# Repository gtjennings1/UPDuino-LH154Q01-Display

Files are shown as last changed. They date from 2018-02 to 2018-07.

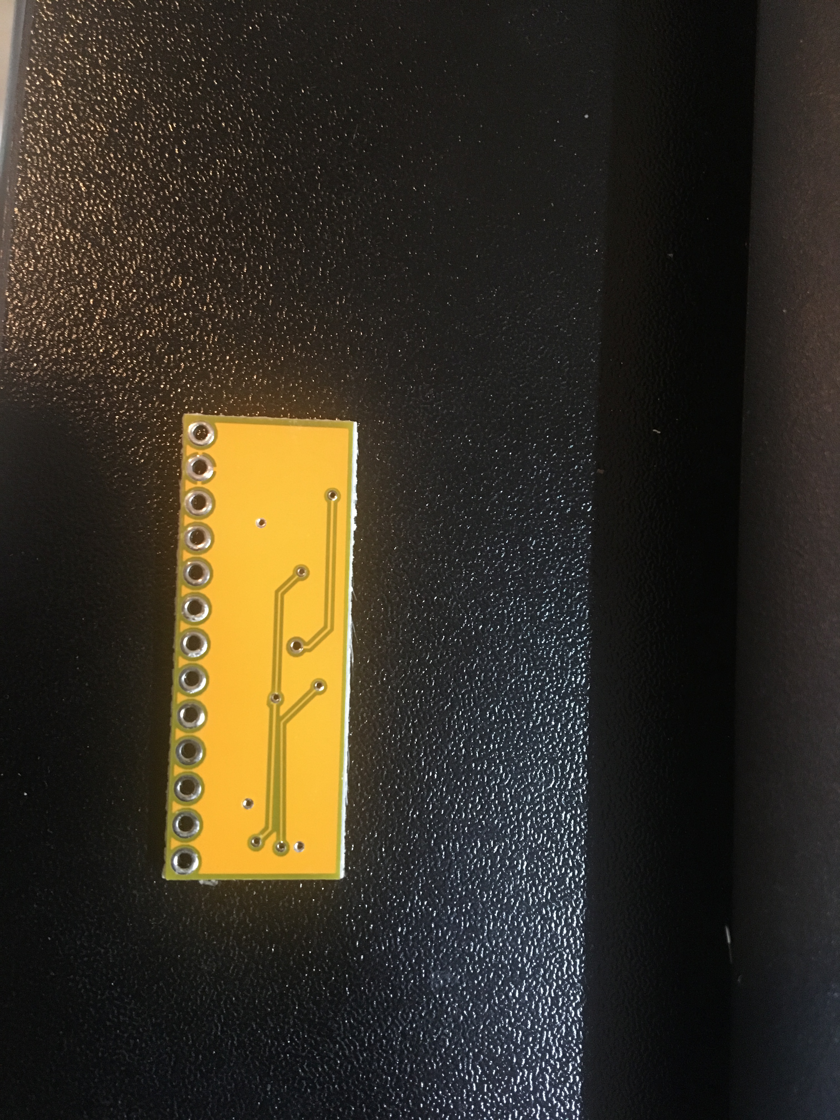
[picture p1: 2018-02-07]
PCB/Images/IMG-0591.JPG

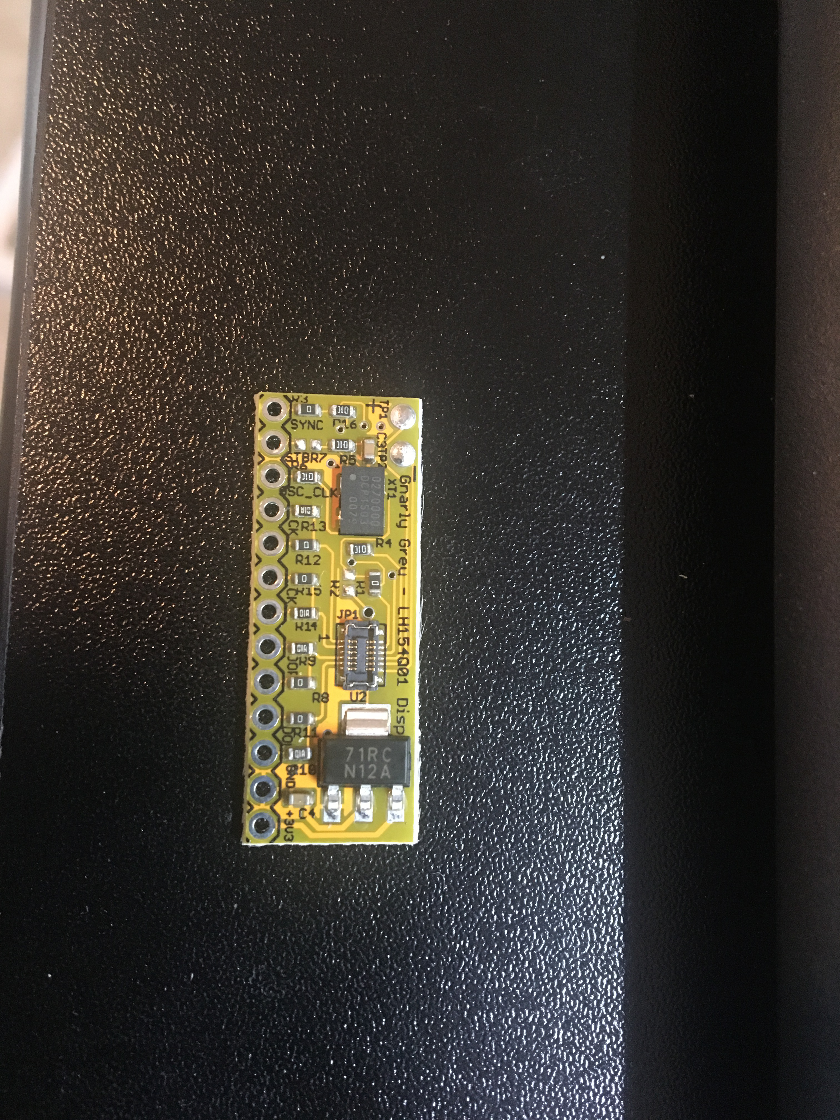
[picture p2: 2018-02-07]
PCB/Images/IMG-0590.JPG

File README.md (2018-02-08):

# UPDuino-LH154Q01-Display
Design to connect Lattice Ultraplus FPGA to LH154Q01 Display

UPDuino is a small maker board with a Lattice Ultraplus mobile FPGA.  The UPDuino LH154 Display Adapter Board provides the ability to attach a small 240x240 24-bit RGB display that has been used for many electronic devices including the iPod Nano (6th generation).  The FPGA can be used as a small graphics processor to deliver interactive graphics, bitmaps, fonts/text on the display.

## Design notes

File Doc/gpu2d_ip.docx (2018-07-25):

Gnarly Grey 2D GPU IP

7/25/18

The Gnarly Grey 2D GPU IP supports acceleration functions for drawing line, rectangle, circle, triangle and filling up rectangle, circle and triangle inside a very small Lattice Ultraplus 5K LUT FPGA. There’s also support for mono-color 64x64 pixel bitmap and fonts with variable size. The GPU can be controlled with very simple interface like UART to receive its commands or register configurations with very low bandwidth. Rendered graphics from these settings are passed to a RAM/Display Buffer. Current implementation of supports 12-bit (4096) colors (4-bits for R, G, B each).

IP Block Diagram

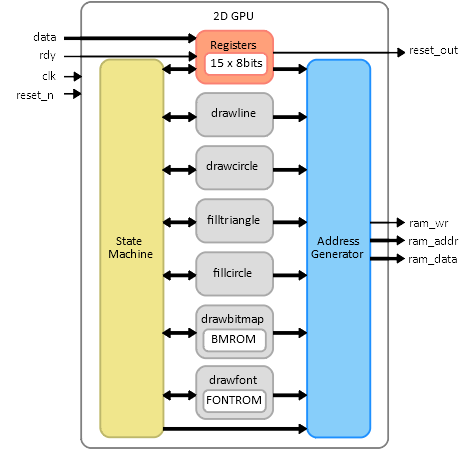
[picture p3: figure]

The GPU IP has 15 registers to store information related to GPU task such as graphic coordinates, GPU functions to be execute, color bitmap number, font character and size, etc. Information stored in registers is utilized by a state machine, address generator and acceleration sub modules (drawline, drawcircle, filltriangle, etc.) to perform the given acceleration task. A state machine enables acceleration sub modules based on information configured in the register set and the address generator takes data from acceleration sub module to write rendering information on display buffer.

The GPU IP is designed to take register address and data information from the same input bus. It takes the first data received on the bus as the address and second data received as the data.

There’s facility to connect multiple GPU (up to 15) on same bus and controlling all GPU (Display) simultaneously or individually by using broadcast or individual control/status registers as mentioned in Register Map section. A display number for particular instance can be set by a Verilog parameter at synthesis time. There’s also a Verilog parameter for rotation, in case other than 0 degree rotation is required.

Port and Parameter Details:

Name | Type | Size (bits) | Description
ROTATION | Parameter | 2 | 2’b00 – 0 degree rotation 2’b01 – 90 degree rotation 2’b10 – 180 degree rotation 2’b11 – 270 degree rotation
DISPLAY_NO | Parameter | 4 | Value from 1 (4’h0001) to 15 (4’h1111)
clk | Input | 1 | Clock
reset_n | Input | 1 | Reset – Active Low
rdy | Input | 1 | Ready – Active High
data | Input | 8 | Data – used for register address and data
reset_out | Output | 1 | Reset Out – Active High
ram_wr | Output | 1 | Memory Write Enable – Active High
ram_addr | Output | 20 | Memory Write Address
ram_data | Output | 8 | Memory Write Data

Register Map

Following is description of registers available on IP, all registers take 00h as default value upon reset.

Register Address 00h – Control/Status Register [Boardcast]

Bit 7 | Bit 6 | Bit 5 | Bit 4 | Bit 3 | Bit 2 | Bit 1 | Bit 0
START | BUSY | RESET | NU | FUN[3] | FUN[2] | FUN[1] | FUN[0]

| FUN[3:0] 0000 0001 0010 0011 0100 0101 0110 0111 1000 1001 | Draw Function pixel line rectangle triangle circle fill rectangle fill triangle fill circle bitmap font
| NU | Not Used
| RESET 0 1 | Reset GPU and generate reset_out No effect Reset, self clearing
| BUSY 0 1 | GPU busy status GPU is free to accept new request GPU is busy
| START 0 1 | Trigger/Start execution of acceleration function No effect Start, self clearing

Register Address 01h – Red Color Register

Bit 7 | Bit 6 | Bit 5 | Bit 4 | Bit 3 | Bit 2 | Bit 1 | Bit 0
RED[3] | RED[2] | RED[1] | RED[0] | NU | NU | NU | NU

| NU | Not Used
| RED[3:0] | Red Color Value (0 to 15)

Register Address 02h – Green Color Register

Bit 7 | Bit 6 | Bit 5 | Bit 4 | Bit 3 | Bit 2 | Bit 1 | Bit 0
GREEN[3] | GREEN[2] | GREEN[1] | GREEN[0] | NU | NU | NU | NU

| NU | Not Used
| GREEN[3:0] | Green Color Value (0 to 15)

Register Address 03h – Blue Color Register

Bit 7 | Bit 6 | Bit 5 | Bit 4 | Bit 3 | Bit 2 | Bit 1 | Bit 0
BLUE[3] | BLUE[2] | BLUE[1] | BLUE[0] | NU | NU | NU | NU

| NU | Not Used
| BLUE[3:0] | Blue Color Value (0 to 15)

Register Address 04h – Point 1, X Co-ordinate Register

Bit 7 | Bit 6 | Bit 5 | Bit 4 | Bit 3 | Bit 2 | Bit 1 | Bit 0
X1[7] | X1[6] | X1[5] | X1[4] | X1[3] | X1[2] | X1[1] | X1[0]

| X1[7:0] | Point 1, X Co-ordinate Value (0 to 255)

Register Address 05h – Point 1, Y Co-ordinate Register

Bit 7 | Bit 6 | Bit 5 | Bit 4 | Bit 3 | Bit 2 | Bit 1 | Bit 0
Y1[7] | Y1[6] | Y1[5] | Y1[4] | Y1[3] | Y1[2] | Y1[1] | Y1[0]

| Y1[7:0] | Point 1, Y Co-ordinate Value (0 to 255)

Register Address 06h – Point 2, X Co-ordinate Register

Bit 7 | Bit 6 | Bit 5 | Bit 4 | Bit 3 | Bit 2 | Bit 1 | Bit 0
X2[7] | X2[6] | X2[5] | X2[4] | X2[3] | X2[2] | X2[1] | X2[0]

| X2[7:0] | Point 2, X Co-ordinate Value (0 to 255)

Register Address 07h – Point 2, Y Co-ordinate Register

Bit 7 | Bit 6 | Bit 5 | Bit 4 | Bit 3 | Bit 2 | Bit 1 | Bit 0
Y2[7] | Y2[6] | Y2[5] | Y2[4] | Y2[3] | Y2[2] | Y2[1] | Y2[0]

| Y2[7:0] | Point 2, Y Co-ordinate Value (0 to 255)

Register Address 08h – Point 3, X Co-ordinate Register

Bit 7 | Bit 6 | Bit 5 | Bit 4 | Bit 3 | Bit 2 | Bit 1 | Bit 0
X3[7] | X3[6] | X3[5] | X3[4] | X3[3] | X3[2] | X3[1] | X3[0]

| X3[7:0] | Point 3, X Co-ordinate Value (0 to 255)

Register Address 09h – Point 3, Y Co-ordinate Register

Bit 7 | Bit 6 | Bit 5 | Bit 4 | Bit 3 | Bit 2 | Bit 1 | Bit 0
Y3[7] | Y3[6] | Y3[5] | Y3[4] | Y3[3] | Y3[2] | Y3[1] | Y3[0]

| Y3[7:0] | Point 3, Y Co-ordinate Value (0 to 255)

Register Address 0Ah – Circle Radius Register

Bit 7 | Bit 6 | Bit 5 | Bit 4 | Bit 3 | Bit 2 | Bit 1 | Bit 0
RAD[7] | RAD[6] | RAD[5] | RAD[4] | RAD[3] | RAD[2] | RAD[1] | RAD[0]

| RAD[7:0] | Circle Radius Value (0 to 255)

Register Address 0Bh – Bitmap Number Register

Bit 7 | Bit 6 | Bit 5 | Bit 4 | Bit 3 | Bit 2 | Bit 1 | Bit 0
NU | NU | NU | BMN[4] | BMN[3] | BMN[2] | BMN[1] | BMN[0]

| BMN[4:0] | Bitmap Number Value (0 to 23)
| NU | Not Used

Register Address 0Ch – Font Character Register

Bit 7 | Bit 6 | Bit 5 | Bit 4 | Bit 3 | Bit 2 | Bit 1 | Bit 0
FC[7] | FC[6] | FC[5] | FC[4] | FC[3] | FC[2] | FC[1] | FC[0]

| FC[7:0] | Font Character Value (0 to 255)

Register Address 0Dh – Font Size Register

Bit 7 | Bit 6 | Bit 5 | Bit 4 | Bit 3 | Bit 2 | Bit 1 | Bit 0
NU | NU | NU | FS[4] | FS[3] | FS[2] | FS[1] | FS[0]

| FS[4:0] | Font Size Value (1 to 31)
| NU | Not Used

Register Address X0h – Control/Status Register [Individual], X= Display No (1 to 15)

Bit 7 | Bit 6 | Bit 5 | Bit 4 | Bit 3 | Bit 2 | Bit 1 | Bit 0
START | BUSY | RESET | NU | FUN[3] | FUN[2] | FUN[1] | FUN[0]

| FUN[3:0] 0000 0001 0010 0011 0100 0101 0110 0111 1000 1001 | Draw Function pixel line rectangle triangle circle fill rectangle fill triangle fill circle bitmap font
| NU | Not Used
| RESET 0 1 | Reset GPU and generate reset_out No effect Reset, self clearing
| BUSY 0 1 | GPU busy status GPU is free to accept new request GPU is busy
| START 0 1 | Trigger/Start execution of acceleration function No effect Start, self clearing

Typical System Example:

In this example, a typical system using 2D GPU is showcased. The system consist of a microcontroller such as an Arduino Nano ATMega328 with a UART interface connected to Upduino v1.0 or v2.0 board. A LH154Q01 Display Adapter for UPDuino boards is used to connected a 240x240 pixel MIPI display on one end to the Upduino v1.0 or v2.0 board.

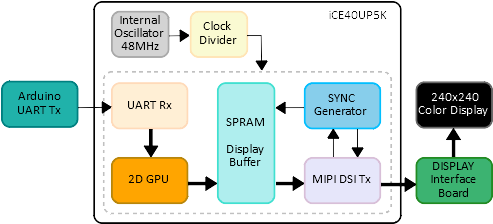
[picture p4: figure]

In this typical setup, Arduino Nano microcontroller is the host controller which control’s operation of GPU. Inside the iCE40UP5K FPGA, small UART receiver is used to receive commands from Arduino over UART and provide it to the 2D GPU. The 2D GPU is connected with 128kB Display Buffer (SPRAM) available on FPGA itself. The display buffer is accessed by a MIPI DSI transmitter design to send display buffer data to the 240x240 pixel color display through MIPI display interface board. SYNC Generator controls timing of sending display buffer to MIPI display.

The following are some typical examples of the GPU commands issued by the microcontroller over UART:

1. Draw a line from p1(10,20) to p2(50,60) with color Red.

Serial.write(0x04); //Register address for P1-x

Serial.write(0x0A); //Register data for P1-x

Serial.write(0x05); //Register address for P1-y

Serial.write(0x14); //Register data for P1-y

Serial.write(0x06); //Register address for P2-x

Serial.write(0x32); //Register data for P2-x

Serial.write(0x07); //Register address for P2-y

Serial.write(0x3C); //Register data for P2-y

Serial.write(0x01); //Register address for Red color

Serial.write(0xFF); //Register data for Red color

Serial.write(0x02); //Register address for Green color

Serial.write(0x00); //Register data for Green color

Serial.write(0x03); //Register address for Blue Color

Serial.write(0x00); //Register data for Blue Color

Serial.write(0x00); //Register address for Control/Status Register

Serial.write(0x81); //Register data for Control/Status Register to draw line

2. Draw a Yellow color filled triangle with p1(10,20), p2(50, 60), p3(10, 60)

Serial.write(0x04); //Register address for P1-x

Serial.write(0x0A); //Register data for P1-x

Serial.write(0x05); //Register address for P1-y

Serial.write(0x14); //Register data for P1-y

Serial.write(0x06); //Register address for P2-x

Serial.write(0x32); //Register data for P2-x

Serial.write(0x07); //Register address for P2-y

Serial.write(0x3C); //Register data for P2-y

Serial.write(0x08); //Register address for P3-x

Serial.write(0x0A); //Register data for P3-x

Serial.write(0x09); //Register address for P3-y

Serial.write(0x3C); //Register data for P3-y

Serial.write(0x01); //Register address for Red color

Serial.write(0xFF); //Register data for Red color

Serial.write(0x02); //Register address for Green color

Serial.write(0xFF); //Register data for Green color

Serial.write(0x03); //Register address for Blue Color

Serial.write(0x00); //Register data for Blue Color

Serial.write(0x00); //Register address for Control/Status Register

Serial.write(0x86); //Register data for Control/Status Register to fill triangle

3. Draw a bitmap number 5 at p1(10,20) with SkyBlue color

Serial.write(0x04); //Register address for P1-x

Serial.write(0x0A); //Register data for P1-x

Serial.write(0x05); //Register address for P1-y

Serial.write(0x14); //Register data for P1-y

Serial.write(0x01); //Register address for Red color

Serial.write(0x00); //Register data for Red color

Serial.write(0x02); //Register address for Green color

Serial.write(0xFF); //Register data for Green color

Serial.write(0x03); //Register address for Blue Color

Serial.write(0xFF); //Register data for Blue Color

Serial.write(0x0B); //Register address for Bitmap Number

Serial.write(0x05); //Register data for Bitmap Number

Serial.write(0x00); //Register address for Control/Status Register

Serial.write(0x88); //Register data for Control/Status Register to draw bitmap

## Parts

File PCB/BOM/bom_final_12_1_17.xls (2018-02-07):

EXAMPLE BILL OF MATERIALS (BOM)
Place your mouse over the red comment markers in the top right corner of the cells in the row below to see more info on the data in that column
1 | 2 | 3 | 4 | 5 | 6 | 7 | 8 | 9 | 10 | 11
Sequential Item Nos | Consolidated quantity of each Part No | Component ID's separated by Commas | Confirmation Yes or No Parts are fitted this Build (Note 1) | Full Description of Part e.g. for capacitor include value, tolerance and type or Dielectric | Value or Type No | Case Style | Supplier or Manufacturer (Note 2) | Supplier Stock No or Manufacturer's Part No (Note 2) | Side of Board Mounted | PTH or SMT
Item | Qty | Reference | Fit | Part Description | Value | Package | Supplier | Supplier Ref | Side | Mount Type
1 | 2 | C3, C4 | Y | cap | 0.1uF | Capacitor |  | 402 | T | S
2 | 1 | JP1 | Y | connector for display | 5035481220 | Connector |  |  | T | S
3 | 1 | JP2 | N | .1" header | DNI | 13-pin single row .1" header |  |  | T | P
4 | 8 | R1, R3, R8, R11, R12, R15, R6, R7 | Y | 0 ohm resistor | 0 | Resistor |  | 402 | T | S
5 | 1 | R2 | N | DNI resistors | DNI | Resistor |  | 402 | T | S
6 | 4 | R4, R5, R16 | Y | 10k resistors | 10k | Resistor |  | 402 | T | S
7 | 4 | R9, R10, R13, R14 | Y | 100 ohm resistors | 100 | Resistor |  | 402 | T | S
8 | 1 | U2 | Y | 1.8V regulator | LM1117MPX-1.8/NOPB | Voltage Regulator LM1117 |  | VREG-08170 | T | S
9 | 1 | XT1 | Y | 27Mhz Osc. | ASFLMB-50.000MHZ-LC-T |  |  | Use this osc or equivlent with same pinout | T | S

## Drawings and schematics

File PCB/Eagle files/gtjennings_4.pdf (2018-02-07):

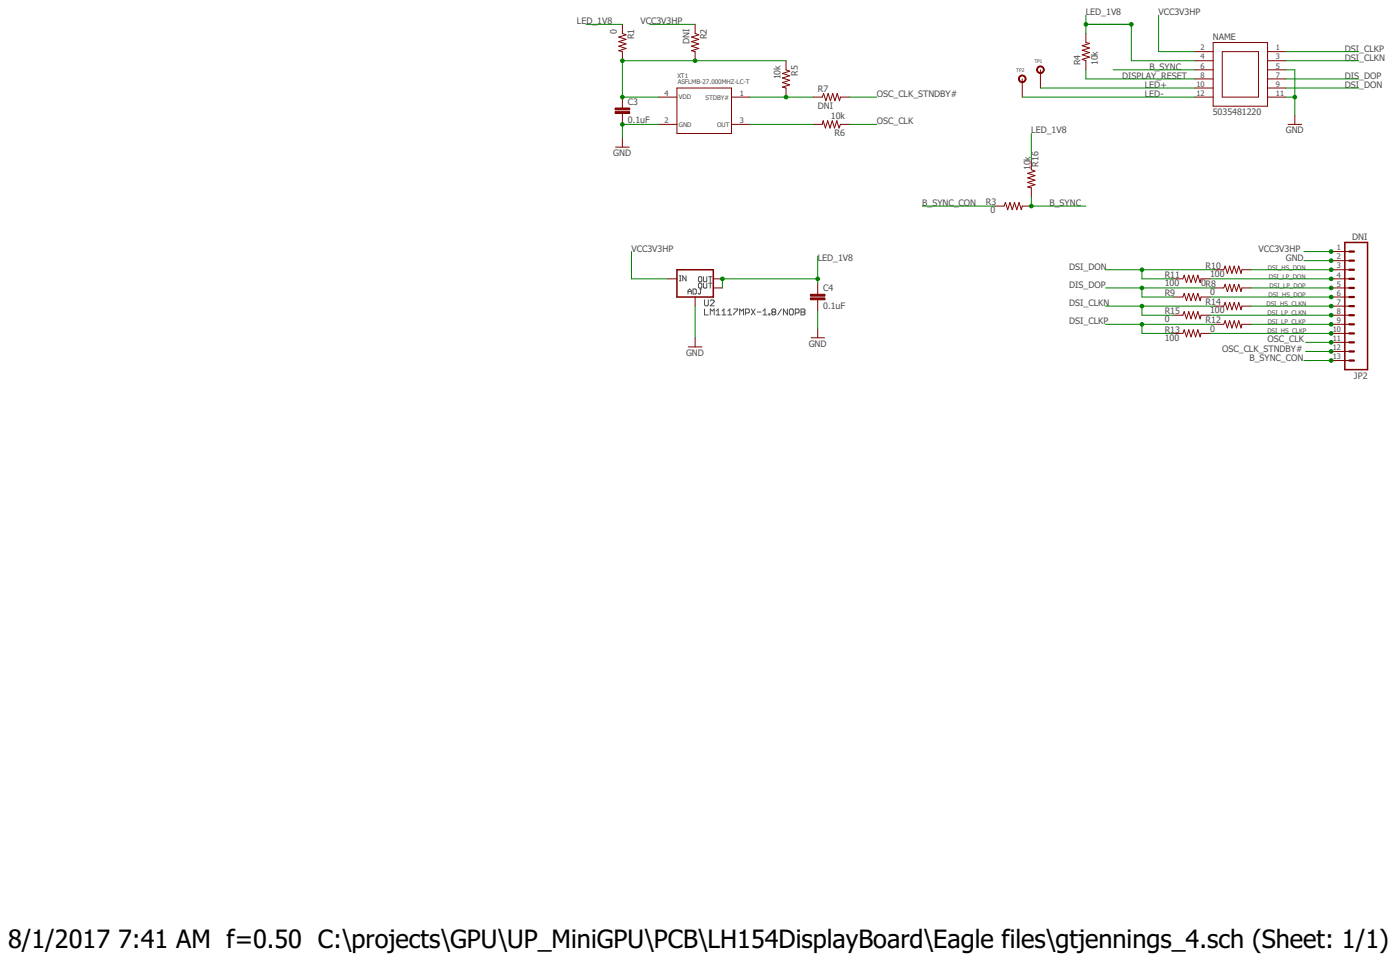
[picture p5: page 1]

8/1/2017 7:41 AM f=0.50 C:\projects\GPU\UP_MiniGPU\PCB\LH154DisplayBoard\Eagle files\gtjennings_4.sch (Sheet: 1/1)

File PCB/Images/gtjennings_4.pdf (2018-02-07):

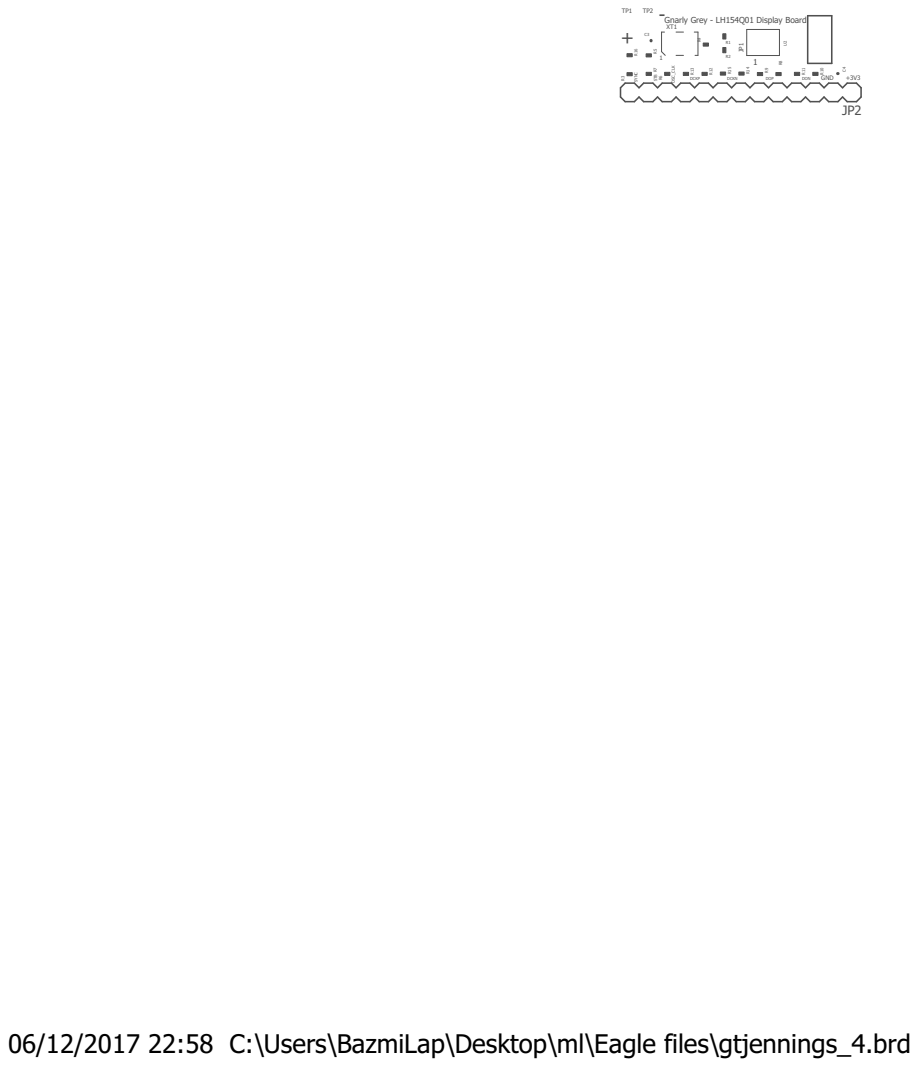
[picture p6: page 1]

-Gnarly Grey - LH154Q01 Display Board

06/12/2017 22:58 C:\Users\BazmiLap\Desktop\ml\Eagle files\gtjennings_4.brd

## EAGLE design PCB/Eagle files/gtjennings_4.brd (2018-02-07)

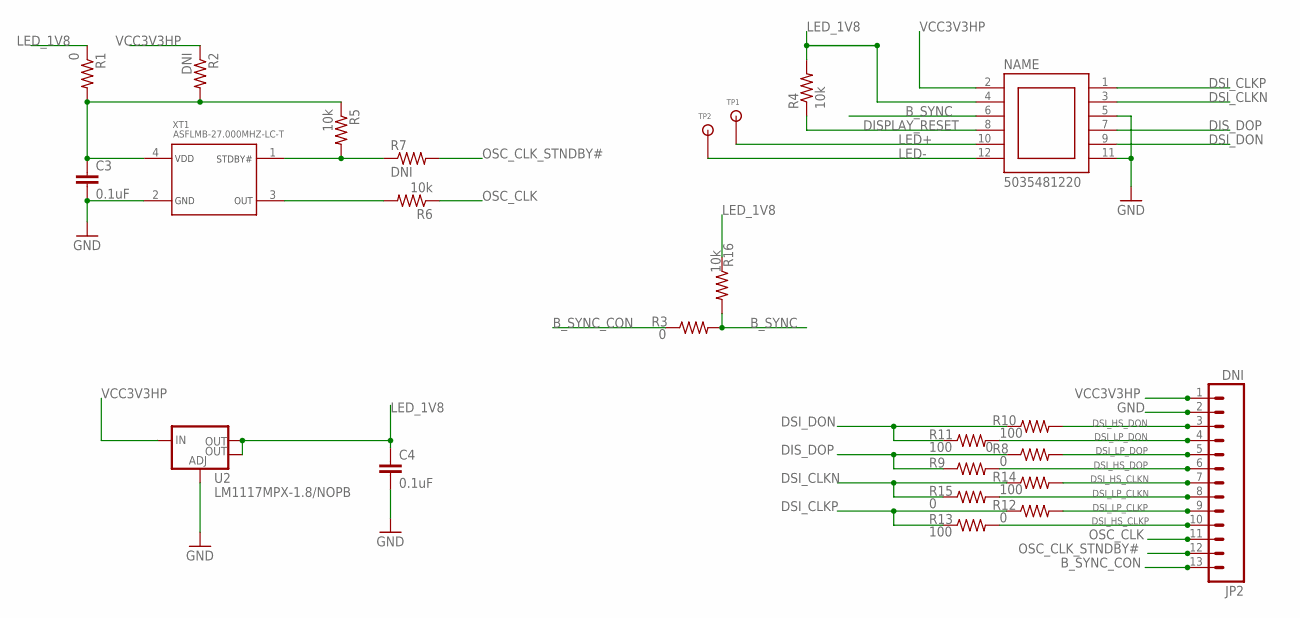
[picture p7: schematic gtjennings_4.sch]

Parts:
C3, C4: 0.1uF; 0402-CAP
JP1: 5035481220
JP2: DNI; 1X13
R1, R3, R8, R11, R12, R15: 0; 0402-RES
R2, R7: DNI; 0402-RES
R4, R5, R6, R16: 10k; 0402-RES
R9, R10, R13, R14: 100; 0402-RES
TP1, TP2: TP
U2: LM1117MPX-1.8/NOPB; SOT223
XT1: ASFLMB-27.000MHZ-LC-T

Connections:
B_SYNC: JP1.6, R3.2, R16.2
B_SYNC_CON: JP2.13, R3.1
DISPLAY_RESET: JP1.8, R4.1
DIS_DOP: JP1.7, R8.1, R9.1
DSI_CLKN: JP1.3, R14.1, R15.1
DSI_CLKP: JP1.1, R12.1, R13.1
DSI_DON: JP1.9, R10.1, R11.1
DSI_HS_CLKN: JP2.7, R14.2
DSI_HS_CLKP: JP2.10, R13.2
DSI_HS_DON: JP2.3, R10.2
DSI_HS_DOP: JP2.6, R9.2
DSI_LP_CLKN: JP2.8, R15.2
DSI_LP_CLKP: JP2.9, R12.2
DSI_LP_DON: JP2.4, R11.2
DSI_LP_DOP: JP2.5, R8.2
GND: C3.2, C4.2, JP1.5, JP1.11, JP2.2, U2.1 (ADJ), XT1.2
LED+: JP1.10, TP1.1
LED-: JP1.12, TP2.1
LED_1V8: C4.1, JP1.4, R1.1, R4.2, R16.1, U2.2 (OUT), U2.4 (OUT)
unnamed: R5.2, R7.1, XT1.1
OSC_CLK: JP2.11, R6.1
OSC_CLK6: R6.2, XT1.3
OSC_CLK_STNDBY#: JP2.12, R7.2
OSC_PWR: C3.1, R1.2, R2.2, R5.1, XT1.4
VCC3V3HP: JP1.2, JP2.1, R2.1, U2.3 (IN)

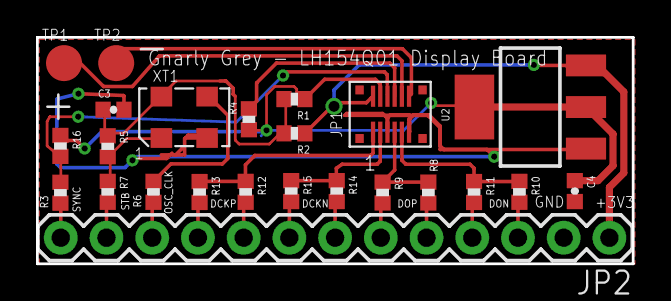
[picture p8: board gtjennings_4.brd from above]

Board: 2 copper layers, 33.1 x 12.6 mm, 24 parts (0 on the bottom side), 25 nets.

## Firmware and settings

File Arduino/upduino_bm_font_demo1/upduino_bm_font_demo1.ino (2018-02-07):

/******************************************************************************
Copyright 2017 Gnarly Grey LLC

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
THE SOFTWARE IS PROVIDED "AS IS", WITHOUT WARRANTY OF ANY KIND, EXPRESS OR
IMPLIED, INCLUDING BUT NOT LIMITED TO THE WARRANTIES OF MERCHANTABILITY,
FITNESS FOR A PARTICULAR PURPOSE AND NONINFRINGEMENT. IN NO EVENT SHALL THE
AUTHORS OR COPYRIGHT HOLDERS BE LIABLE FOR ANY CLAIM, DAMAGES OR OTHER
LIABILITY, WHETHER IN AN ACTION OF CONTRACT, TORT OR OTHERWISE, ARISING FROM,
OUT OF OR IN CONNECTION WITH THE SOFTWARE OR THE USE OR OTHER DEALINGS IN THE
SOFTWARE.
******************************************************************************/

#include "Adafruit_GFX.h"
#include "gfxfont.h"
#include "FreeSans9pt7b.h"
#include "FreeSansBold12pt7b.h"
#include "bitmap.h"

Adafruit_GFX tft = Adafruit_GFX(240, 240);

unsigned int i, j, fg;
int k;
long time_stamp;
String stringText;
  

void setup(){

  Serial.begin(1000000);
  Serial.write(0x00);
  Serial.write(0x20);
  time_stamp = millis();
  while((millis() - time_stamp) < 100); 

  tft.fillScreen(0x0000);
    
  tft.drawBitmap(56, 56, call2BM, 128 , 128, 0x22F);

  stringText = "Gnarly Grey";
  tft.setFont(&FreeSansBold12pt7b); 
  tft.setTextSize(1);
  tft.setCursor(50, 210); 
  tft.print(stringText); 

  stringText = "INCOMING CALL";
  tft.setFont(&FreeSans9pt7b); 
  tft.setCursor(47, 40);
  tft.setTextColor(0x0000, 0x000);
  tft.setTextSize(1);
  tft.print(stringText);

  tft.drawTriangle(184,115, 184,125, 193,120, 0x0F0);
  tft.drawTriangle(194,115, 194,125, 203,120, 0x0F0);
  tft.drawTriangle(204,115, 204,125, 213,120, 0x0F0);
  tft.fillTriangle(214,115, 214,125, 223,120, 0x0F0);

  tft.drawTriangle(55,115, 55,125, 46,120, 0xF00);
  tft.drawTriangle(45,115, 45,125, 36,120, 0xF00);
  tft.drawTriangle(35,115, 35,125, 26,120, 0xF00);
  tft.fillTriangle(25,115, 25,125, 16,120, 0xF00);
  i=0; 
  j=0;  
  k=1;
}

void loop(){

  tft.setCursor(47, 40);
  fg = ((j&0xF)<<8) | ((j&0xF)<<4) | ((j&0xF));
  tft.setTextColor(fg , 0x000); 
  tft.print(stringText);
  switch ((i&0x6)>>1)
  { 
    case 0  :   tft.drawTriangle(184,115, 184,125, 193,120, 0x0F0);
                tft.drawTriangle(194,115, 194,125, 203,120, 0x0F0);
                tft.fillTriangle(204,115, 204,125, 213,120, 0x000);
                tft.drawTriangle(204,115, 204,125, 213,120, 0x0F0);
                tft.fillTriangle(214,115, 214,125, 223,120, 0x0F0);
              
                tft.drawTriangle(55,115, 55,125, 46,120, 0xF00);
                tft.drawTriangle(45,115, 45,125, 36,120, 0xF00);
                tft.fillTriangle(35,115, 35,125, 26,120, 0x000);
                tft.drawTriangle(35,115, 35,125, 26,120, 0xF00);
                tft.fillTriangle(25,115, 25,125, 16,120, 0xF00);
                break;
    case 1  :   tft.fillTriangle(184,115, 184,125, 193,120, 0x0F0);
                tft.drawTriangle(194,115, 194,125, 203,120, 0x0F0);
                tft.drawTriangle(204,115, 204,125, 213,120, 0x0F0);
                tft.fillTriangle(214,115, 214,125, 223,120, 0x000);
                tft.drawTriangle(214,115, 214,125, 223,120, 0x0F0);
              
                tft.fillTriangle(55,115, 55,125, 46,120, 0xF00);
                tft.drawTriangle(45,115, 45,125, 36,120, 0xF00);
                tft.drawTriangle(35,115, 35,125, 26,120, 0xF00);
                tft.fillTriangle(25,115, 25,125, 16,120, 0x000);
                tft.drawTriangle(25,115, 25,125, 16,120, 0xF00);
                break;
    case 2  :   tft.fillTriangle(184,115, 184,125, 193,120, 0x000);
                tft.drawTriangle(184,115, 184,125, 193,120, 0x0F0);
                tft.fillTriangle(194,115, 194,125, 203,120, 0x0F0);
                tft.drawTriangle(204,115, 204,125, 213,120, 0x0F0);
                tft.drawTriangle(214,115, 214,125, 223,120, 0x0F0);
              
                tft.fillTriangle(55,115, 55,125, 46,120, 0x000);
                tft.drawTriangle(55,115, 55,125, 46,120, 0xF00);
                tft.fillTriangle(45,115, 45,125, 36,120, 0xF00);
                tft.drawTriangle(35,115, 35,125, 26,120, 0xF00);
                tft.drawTriangle(25,115, 25,125, 16,120, 0xF00);
                break;
    case 3  :   tft.drawTriangle(184,115, 184,125, 193,120, 0x0F0);
                tft.fillTriangle(194,115, 194,125, 203,120, 0x000);
                tft.drawTriangle(194,115, 194,125, 203,120, 0x0F0);
                tft.fillTriangle(204,115, 204,125, 213,120, 0x0F0);
                tft.drawTriangle(214,115, 214,125, 223,120, 0x0F0);
              
                tft.drawTriangle(55,115, 55,125, 46,120, 0xF00);
                tft.fillTriangle(45,115, 45,125, 36,120, 0x000);
                tft.drawTriangle(45,115, 45,125, 36,120, 0xF00);
                tft.fillTriangle(35,115, 35,125, 26,120, 0xF00);
                tft.drawTriangle(25,115, 25,125, 16,120, 0xF00);
                break;
    default :   tft.drawTriangle(184,115, 184,125, 193,120, 0x0F0);
                tft.drawTriangle(194,115, 194,125, 203,120, 0x0F0);
                tft.drawTriangle(204,115, 204,125, 213,120, 0x0F0);
                tft.fillTriangle(214,115, 214,125, 223,120, 0x0F0);
              
                tft.drawTriangle(55,115, 55,125, 46,120, 0xF00);
                tft.drawTriangle(45,115, 45,125, 36,120, 0xF00);
                tft.drawTriangle(35,115, 35,125, 26,120, 0xF00);
                tft.fillTriangle(25,115, 25,125, 16,120, 0xF00);
                break;
  }

  i++;
  if (j==15)
    k = -1;
  if (j==0)
    k = 1;
  j=j+k;  
    
}

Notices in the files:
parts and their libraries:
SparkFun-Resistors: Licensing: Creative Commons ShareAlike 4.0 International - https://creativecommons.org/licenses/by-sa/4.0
